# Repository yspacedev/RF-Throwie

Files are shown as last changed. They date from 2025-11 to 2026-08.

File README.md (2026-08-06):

## About
The RF throwie is an ultra-cheap sub-GHz transmitter using the CMOSTek/HopeRF $1 CMT2119A RF transmitter and $0.10 CH32V003 32-bit RISC-V microcontroller on a 20x20mm 2-layer board.

Called a "throwie" because it's designed to be cheap enough (almost disposable) that you can throw it anywhere for a foxhunt or other RF application.

The CMT2119A supports (G)FSK/OOK modulation and a tuning range of 157MHz - 1297MHz (according to G4EML). While it's meant to be configured with CMOSTek's RFPDK and their proprietary software, it can be configured in-situ though a 2-wire interface that writes to registers on the chip. The registers have been partly reverse engineered in https://github.com/g4eml/RP2040_Synth, and this project aims to reverse engineer them more fully to allow for full customization without the RFPDK. The CMT2119A can also be used as a general-purpose frequency synthesizer, which opens up a lot of possibilities for cheap SDRs and custom RF frontends. 

### Firmware

The CH32V003 is programmed with cnlohr's ch32fun stack and uses bitbanging to generate the TWI signals. The current firmware transmits Morse code on the UHF ham radio band (70cm band) that can be picked up by an SDR using NBFM demodulation or a cheap handheld transciever like a Baofeng or Quansheng UV-K5. In theory more modulations are possible, including FSK-based modes. However, due to the long (370us) tuning time and coarse frequency resolution (200~400Hz) of the frequency synthesizer, phase modulation through frequency modulation is likely not possible with unmodified hardware. Maybe using a bitstream to generate harmonics and then filtering before feeding into the reference oscillator input could result in a fine frequency resolution on inexpensive hardware, but this has yet to be tested.

For development and compilation, you will need to set up CH32fun per the instructions on their github. If you use clangd or Microsoft Intellisense with VSCode/VSCodium, those options are already set up, but you will need to change the path for the libraries or use `compiledb make` to generate the `compile_commands.json` file.

### Board/hardware

The RF throwie board itself supports an input voltage of 3.7v - 18v, and has an onboard LED and the CH32V003 UART interface exposed. There are also 2 jumpers on the back that connect the UART pins to the CMT2119A TWI pins to turn it into a breakout board. For the RF chip, there's a up to 7th order LC filter and matching network feeding an SMA connector or simple wire antenna.

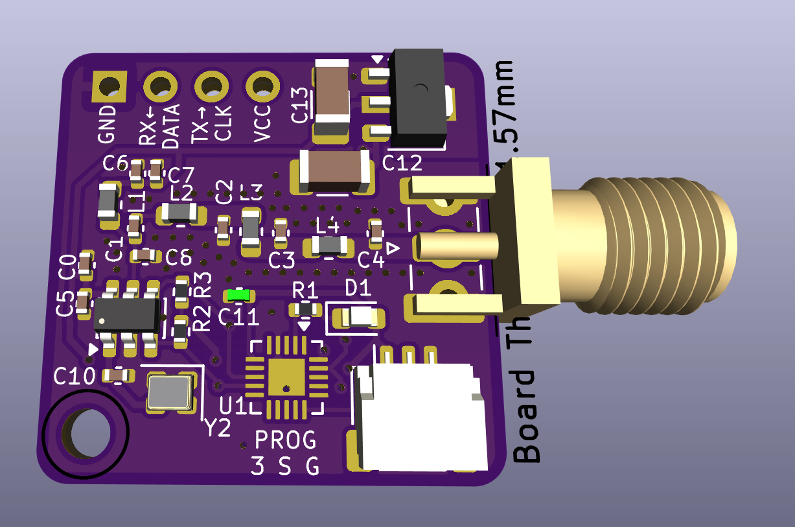
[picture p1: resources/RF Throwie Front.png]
Board Front

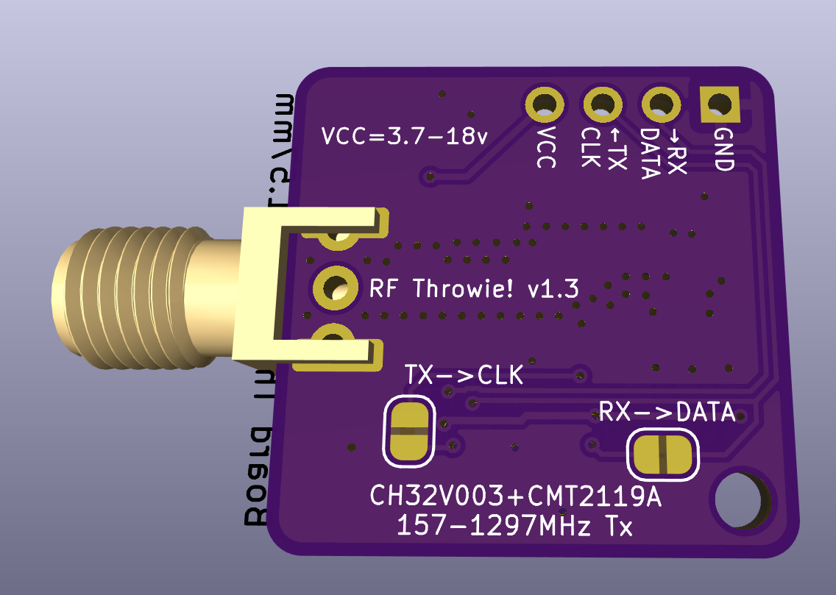
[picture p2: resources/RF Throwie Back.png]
Board Back

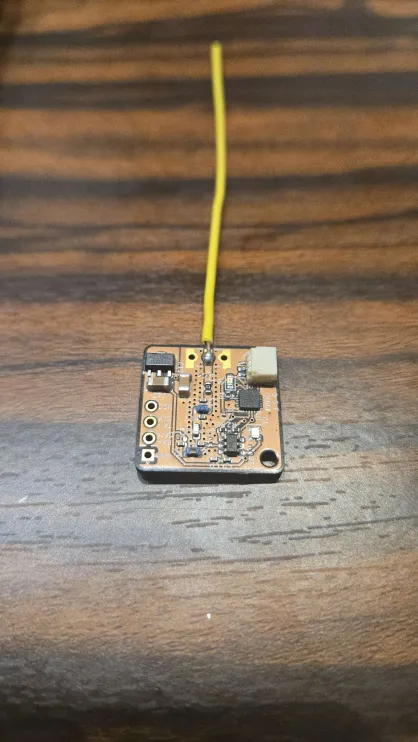
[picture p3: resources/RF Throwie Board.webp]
Board Image


## Tuning

The RF output pin has a frequency dependent impedance, and since CMOSTek only provided the impedance at 4 test frequencies, I used a Python curve fitter to get an empirical equation for the output impedance. This Desmos graph implements the formula: https://www.desmos.com/calculator/a3xyh0sjgi

To create a custom matching network for the transmitter, use https://home.sandiego.edu/~ekim/e194rfs01/jwmatcher/matcher2.html to create a match to 50 ohms and then use https://markimicrowave.com/technical-resources/tools/lc-filter-design-tool/ to generate a filter network.

## Extra Information

Extra information like LCSC part numbers for certain components is included in the KiCAD schematic.

It's designed to be fabricated on a 1.6mm FR4 2 layer board.

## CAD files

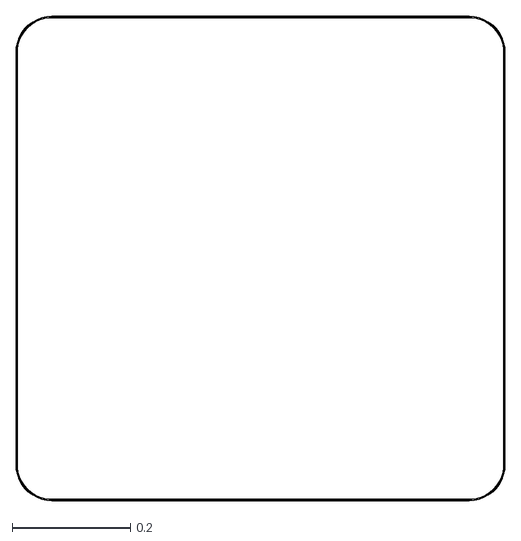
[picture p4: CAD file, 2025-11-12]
hardware/stencil/RF Throwie!-Edge_Cuts.dxf
0.826 x 0.818

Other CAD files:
hardware/stencil/RF Throwie!-F_Paste.dxf

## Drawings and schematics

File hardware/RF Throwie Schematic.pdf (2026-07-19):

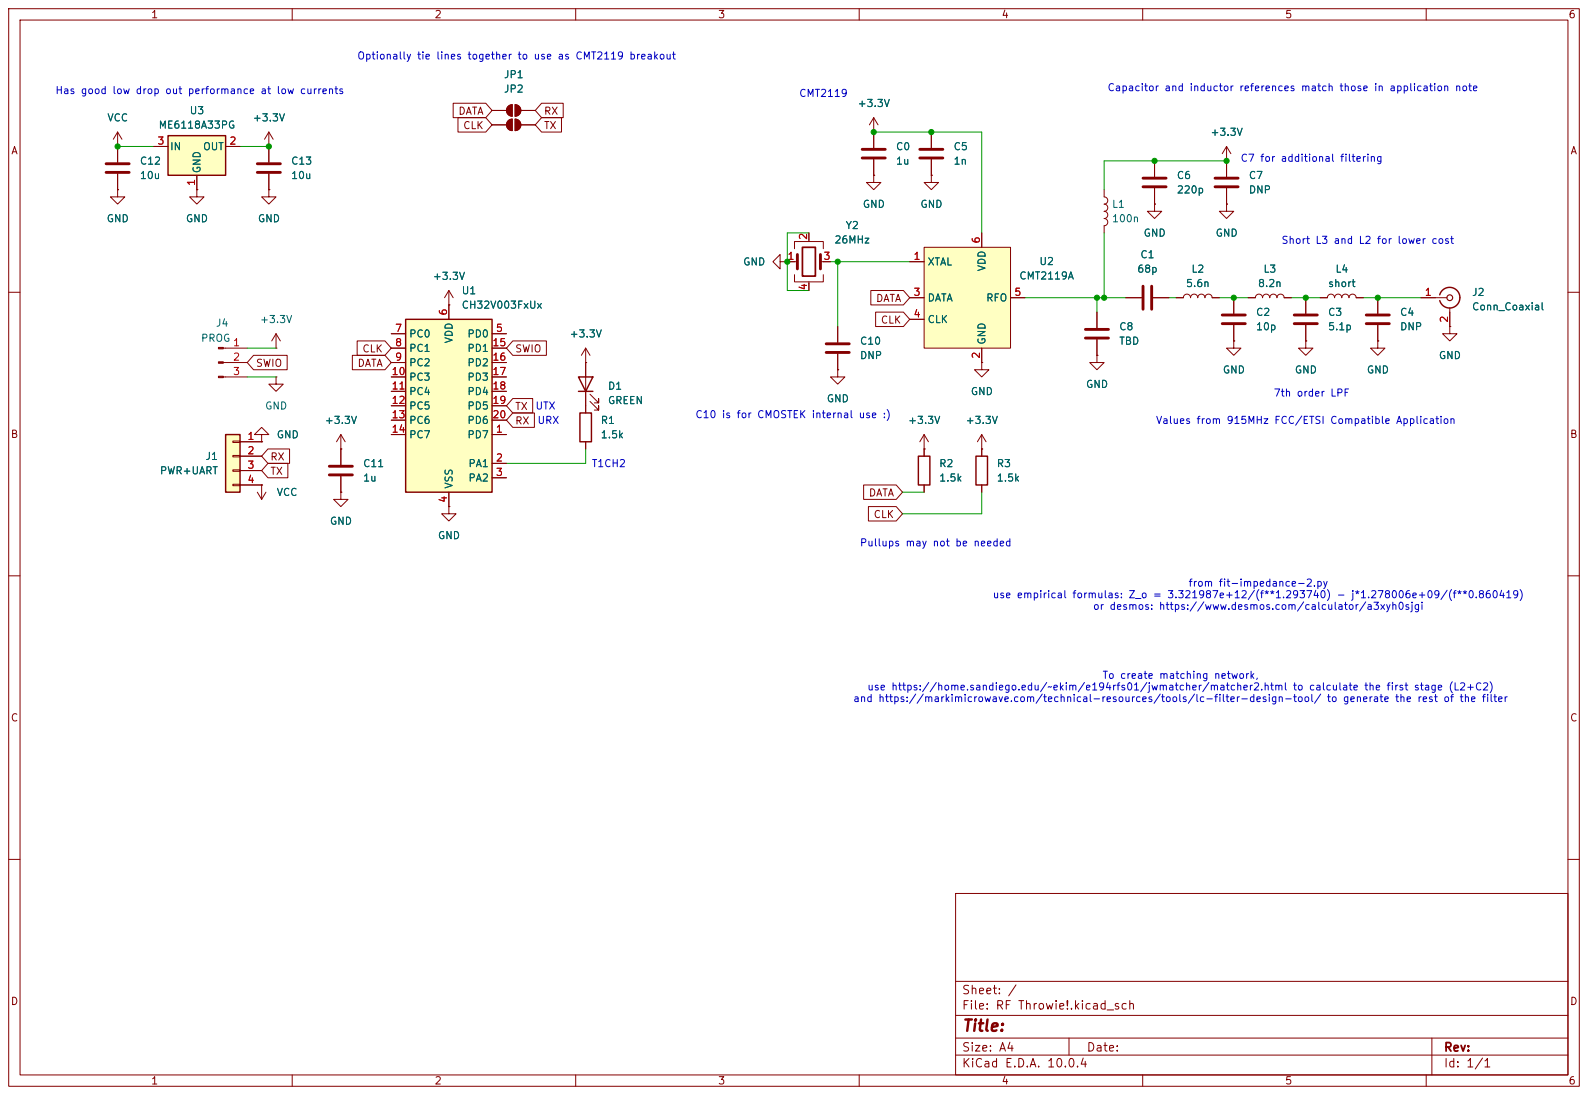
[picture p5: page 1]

Optionally tie lines together to use as CMT2119 breakout

Capacitor and inductor references match those in application note Pullups may not be needed
26MHzGND +3.3V C0

2 DATA 3 CLK 4 RFO 5 VDD

from fit-impedance-2.py use empirical formulas: Z_o = 3.321987e+12/(f**1.293740) - j*1.278006e+09/(f**0.860419) or desmos: https://www.desmos.com/calculator/a3xyh0sjgi

To create matching network, use https://home.sandiego.edu/~ekim/e194rfs01/jwmatcher/matcher2.html to calculate the first stage (L2+C2) and https://markimicrowave.com/technical-resources/tools/lc-filter-design-tool/ to generate the rest of the filter

Size: A4 | Rev:
KiCad E.D.A. 10.0.4 | Id: 1/1

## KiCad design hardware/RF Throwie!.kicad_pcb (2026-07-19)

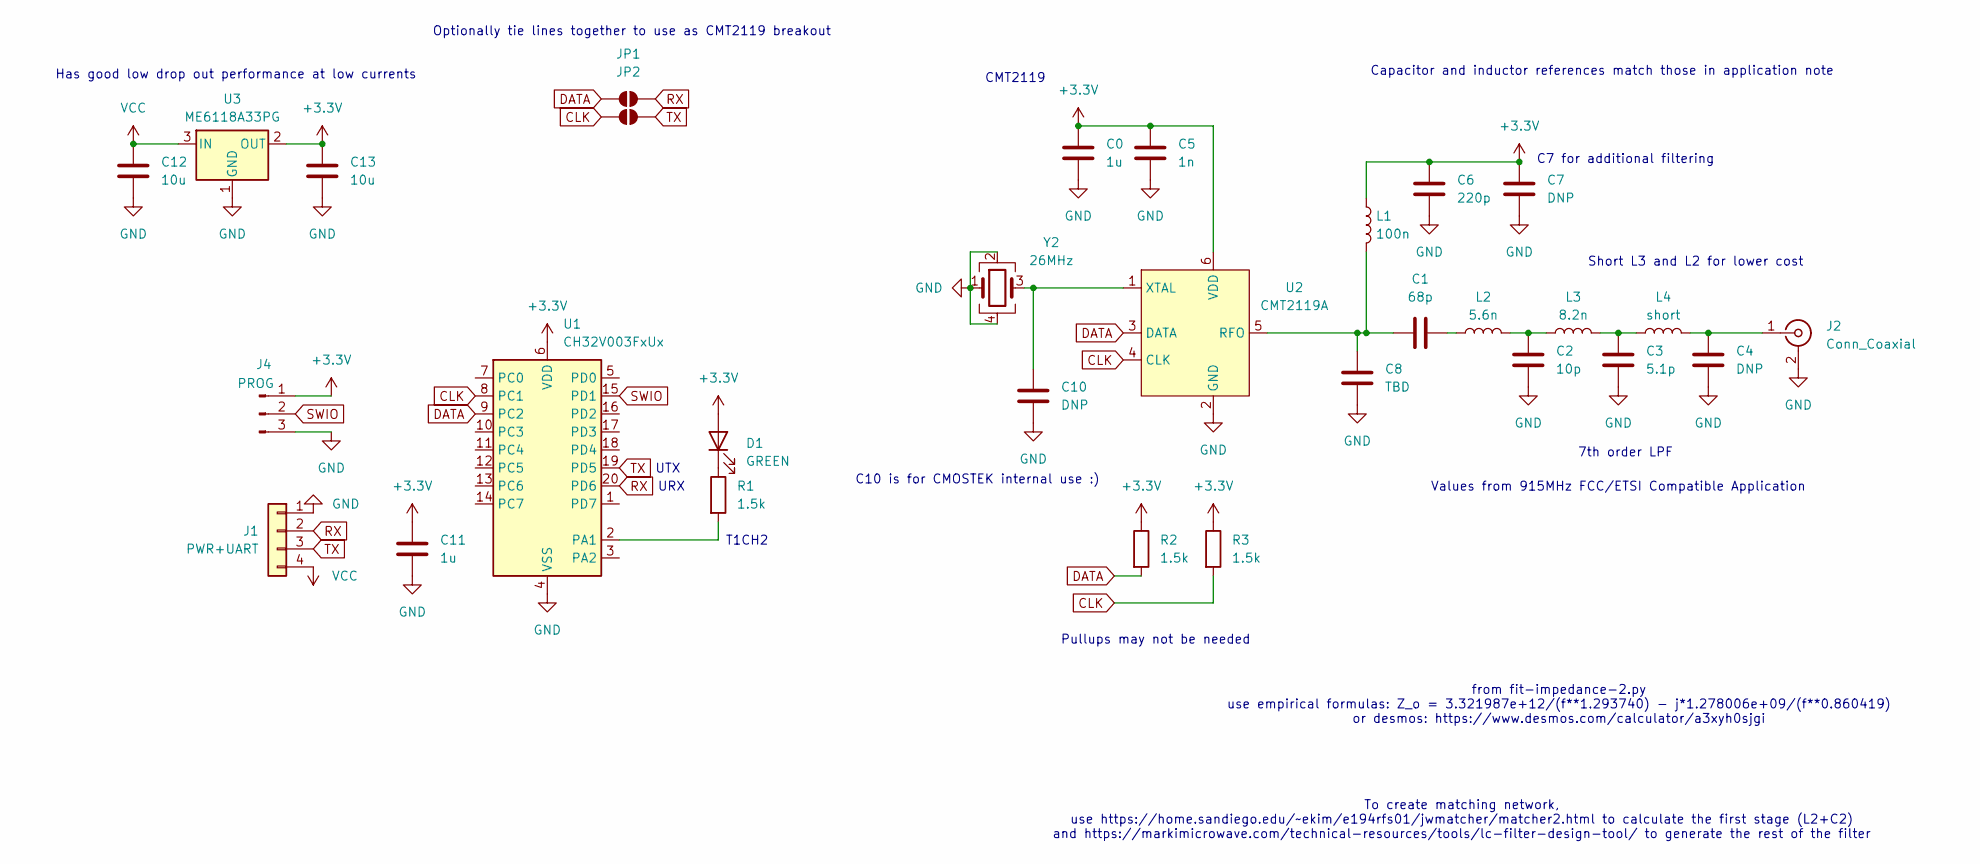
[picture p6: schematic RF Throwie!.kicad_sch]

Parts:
C0, C11: 1u; C_0402_1005Metric
C1: 68p; C_0402_1005Metric
C2: 10p; C_0402_1005Metric
C3: 5.1p; C_0402_1005Metric
C4, C7, C10: DNP; C_0402_1005Metric
C5: 1n; C_0402_1005Metric
C6: 220p; C_0402_1005Metric
C8: TBD; C_0402_1005Metric
C12, C13: 10u; C_1206_3216Metric
D1: GREEN; LED_0603_1608Metric
J1: PWR+UART; PinHeader_1x04_P2.54mm_Vertical
J2: Conn_Coaxial; SMA_Samtec_SMA-J-P-H-ST-EM1_EdgeMount
J4: PROG; JST_SH_SM03B-SRSS-TB_1x03-1MP_P1.00mm_Horizontal
JP1, JP2: SolderJumper_2_Open; SolderJumper-2_P1.3mm_Open_RoundedPad1.0x1.5mm
L1: 100n; L_0603_1608Metric
L2: 5.6n; L_0603_1608Metric
L3: 8.2n; L_0603_1608Metric
L4: short; L_0603_1608Metric
R1, R2, R3: 1.5k; R_0402_1005Metric
U1: CH32V003FxUx; QFN-20-1EP_3x3mm_P0.4mm_EP1.65x1.65mm; LCSC Part Number C5299908
U2: CMT2119A; SOT-23-6; LCSC Part Number C77214
U3: ME6118A33PG; SOT-89-3; LCSC Part Number C236721
Y2: 26MHz; Crystal_SMD_2016-4Pin_2.0x1.6mm; LCSC Part Number C2933002

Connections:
+3.3V: C0.1, C5.1, C6.1, C7.1, C11.1, C13.1, D1.2 (A), J4.1, L1.1, R2.1, R3.1, U1.6 (VDD), U2.6 (VDD), U3.2 (OUT)
CLK: JP2.1 (A), R3.2, U1.8 (PC1), U2.4 (CLK)
DATA: JP1.1 (A), R2.2, U1.9 (PC2), U2.3 (DATA)
GND: C0.2, C2.2, C3.2, C4.2, C5.2, C6.2, C7.2, C8.2, C10.2, C11.2, C12.2, C13.2, J1.1, J2.2 (Ext), J4.3, U1.4 (VSS), U1.21 (VSS), U2.2 (GND), U3.1 (GND), Y2.1, Y2.2, Y2.4
unnamed: C1.2, L2.1
unnamed: C2.1, L2.2, L3.1
unnamed: C3.1, L3.2, L4.1
unnamed: D1.1 (K), R1.1
unnamed: C4.1, J2.1 (In), L4.2
unnamed: R1.2, U1.2 (PA1)
unnamed: C1.1, C8.1, L1.2, U2.5 (RFO)
unnamed: C10.1, U2.1 (XTAL), Y2.3
RX: J1.2, JP1.2 (B), U1.20 (PD6)
SWIO: J4.2, U1.15 (PD1)
TX: J1.3, JP2.2 (B), U1.19 (PD5)
VCC: C12.1, J1.4, U3.3 (IN)

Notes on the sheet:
CMT2119
C10 is for CMOSTEK internal use :)
Pullups may not be needed
7th order LPF
Capacitor and inductor references match those in application note
URX
Has good low drop out performance at low currents
UTX
T1CH2
To create matching network, use https://home.sandiego.edu/~ekim/e194rfs01/jwmatcher/matcher2.html to calculate the first stage (L2+C2) and https://markimicrowave.com/technical-resources/tools/lc-filter-design-tool/ to generate the rest of the filter
C7 for additional filtering
Short L3 and L2 for lower cost
Optionally tie lines together to use as CMT2119 breakout
Values from 915MHz FCC/ETSI Compatible Application
from fit-impedance-2.py use empirical formulas: Z_o = 3.321987e+12/(f**1.293740) - j*1.278006e+09/(f**0.860419) or desmos: https://www.desmos.com/calculator/a3xyh0sjgi

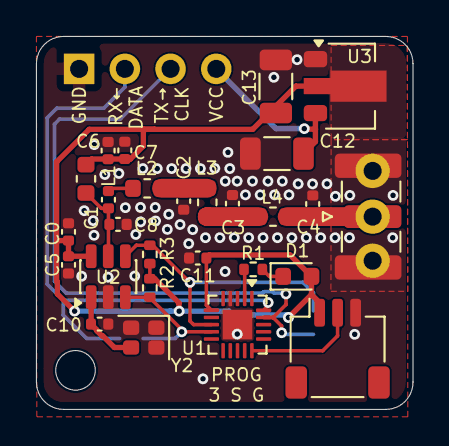
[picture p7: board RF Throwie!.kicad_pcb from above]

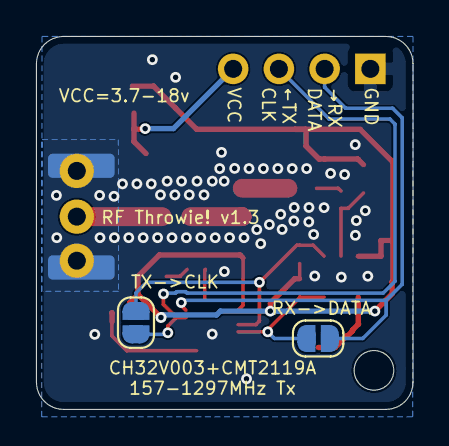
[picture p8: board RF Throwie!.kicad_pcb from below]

Board: 2 copper layers, 20.9 x 20.7 mm, 30 parts (2 on the bottom side), 16 nets.

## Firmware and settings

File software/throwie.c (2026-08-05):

#include "ch32fun.h"
#include "CMT2119A.h"
#include "CMT2119A_TWI.h"
#include "ch32v003hw.h"

#define TONE_HZ 1000
#define CTR_RELOAD (2000000/TONE_HZ)
#define MORSE_WPM 20
//50 units in the word "PARIS"
//50*WPM is the number of units per minute (1/(50*WPM))*MS_PER_MINUTE
#define MORSE_UNIT_MS ((60*1000)/(50*MORSE_WPM))

const char* morse_string = "CALLSIGN TEST"; //replace with your own callsign or change TX_FREQ to an ISM band

//possibly rearrange to map better onto ascii
const char* MORSE_ALPHABET[] = {
    ".-",   // A
    "-...", // B
    "-.-.", // C
    "-..",  // D
    ".",    // E
    "..-.", // F
    "--.",  // G
    "....", // H
    "..",   // I
    ".---", // J
    "-.-",  // K
    ".-..", // L
    "--",   // M
    "-.",   // N
    "---",  // O
    ".--.", // P
    "--.-", // Q
    ".-.",  // R
    "...",  // S
    "-",    // T
    "..-",  // U
    "...-", // V
    ".--",  // W
    "-..-", // X
    "-.--", // Y
    "--..", // Z
	"-----",// 0
	".----",// 1
	"..---",// 2
	"...--",// 3
	"....-",// 4
	".....",// 5
	"-....",// 6
	"--...",// 7
	"---..",// 8
	"----.",// 9
};

char upper(char c){
	if (c>='a' && c<='z'){
		return c - 20;
	}
	return c;
}

uint8_t morse_lookup(char c){
	uint8_t idx = 0;
	char up_char = (char)upper((int)c);
	if (up_char >= '0' && up_char <= '9') {
		idx=up_char-'0'+26;
	} else if (up_char >= 'A' && up_char <= 'Z'){
		idx=up_char-'A';
	}
	return idx;
}

void morse_char(char char_in){
	if (char_in==' '){
		Delay_Ms(6*MORSE_UNIT_MS); //6 units instead of 7 since 1 unit delay comes after every dit or dah
		return;
	}
	uint8_t idx = morse_lookup(char_in);
	
	if (idx>=(sizeof(MORSE_ALPHABET)/sizeof(char*))) return;
	char* code = (char*)MORSE_ALPHABET[idx];
	char c = *code;
	while (c!=0){
		int sym = 1;
		if (c=='.'){
			sym=1;
		} else if (c=='-') {
			sym=3;
		}
		funPinMode(TWIDAT, GPIO_Speed_10MHz | GPIO_CNF_OUT_PP_AF); //switch to timer output
		TIM2->CTLR1 |= TIM_CEN; //enable timer
		Delay_Ms(sym*MORSE_UNIT_MS);
		TIM2->CTLR1 &= ~TIM_CEN; //disable timer
		funPinMode(TWIDAT, FUN_OUTPUT); //switch back to GPIO
		TWI_DAT_HIGH //keep high to prevent transmitter going into sleep mode

		code++;
		c=*code;
		Delay_Ms(1*MORSE_UNIT_MS);
	}
	Delay_Ms(2*MORSE_UNIT_MS);
}

void encode_morse(const char *str){
	char c = *str;
	while (c!=0){
		morse_char(c);
		str++;
		c=*str;
	}
}

//use a timer to modulate the FSK into a continuous tone
void init_tone_timer(void){
	//PC2 has alternate remapping to T2CH2

	//enable AFIO and TIM2
	RCC->APB2PCENR |= RCC_APB2Periph_AFIO | RCC_APB2Periph_GPIOC;
	RCC->APB1PCENR |= RCC_APB1Periph_TIM2;

	//remap alternate function
	AFIO->PCFR1 |= AFIO_PCFR1_TIM2_REMAP_PARTIALREMAP1;

	//reset TIM2
	RCC->APB1PRSTR |= RCC_APB1Periph_TIM2;
	RCC->APB1PRSTR &= ~RCC_APB1Periph_TIM2;

	//Set prescaler
	TIM2->PSC = 23; //divide by 24
	
	TIM2->ATRLR = CTR_RELOAD;

	TIM2->CHCTLR1 |= TIM_OC2M_2 | TIM_OC2M_1 | TIM_OC2PE;

	TIM2->CH2CVR = CTR_RELOAD/2;

	TIM2->CTLR1 |= TIM_ARPE;

	TIM2->CCER |= TIM_CC2E | TIM_CC2P;

	TIM2->SWEVGR |= TIM_UG; //initialize counter
}


#define LED PA1
#define UART_TX PD5
#define UART_RX PD6

int main(){
	SystemInit();

	funGpioInitAll(); // Enable GPIOs
	init_tone_timer();
	funPinMode(LED, FUN_OUTPUT);
	funPinMode(PC2, GPIO_Speed_10MHz | GPIO_CNF_OUT_PP_AF);

	CMT2119A_settings_t tx_settings = {
		.freq_out_hz = 430100000,
		.fsk_dev_hz = 2000,
		.gfsk_rate_bps = 1600, //minimum required for 1khz tone in GFSK mode
		.power_output_dbm = -10,
		.modulation = MOD_FSK,
		.off_time = OFF_90MS,
		.pa_ramp_time = 0,
		.edge_start = EDGE_RISING,
		.invert_symbols = false,
		.xo_current_boost = false,
	};

	CMT2119A_init(PC1, PC2, &tx_settings); //use default frequency

	while(1)
	{
		funDigitalWrite(LED, FUN_LOW);
		//CMT2119A_update(); 
		//frequency can also be changed live, but transmitting the PLL parameters takes more time if we don't need to do so
		TWI_reset();
		Delay_Ms(2);
		CMT2119A_TWI_OFF();
		TWI_DAT_HIGH //wake up from sleep mode
		Delay_Us(1);
		TWI_DAT_LOW
		encode_morse(morse_string);
		TWI_reset(); //turns transmitter off
		//to transmit continuously, leave the DAT pin high
		funDigitalWrite(LED, FUN_HIGH);
		Delay_Ms(1000);
	}
}

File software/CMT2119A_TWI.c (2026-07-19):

#include "CMT2119A_TWI.h"

 uint8_t TWICLK = PC1;
 uint8_t TWIDAT = PC2;

void TWI_init(uint8_t clk_pin, uint8_t dat_pin){
    funGpioInitAll();
    TWICLK = clk_pin;
    TWIDAT = dat_pin;
    TWI_DAT_OUT
    TWI_CLK_OUT
    TWI_DAT_HIGH
    TWI_CLK_HIGH
}


void TWI_Write(uint8_t x){
    TWI_CLK_HIGH
    TWI_DAT_LOW
    for(uint8_t i=0; i<8; ++i){
        TWI_CLK_HIGH
        if(x & 0x80) TWI_DAT_HIGH else TWI_DAT_LOW
        TWI_CYCLE_DELAY
        funDigitalWrite(TWICLK,FUN_LOW); 
        TWI_CYCLE_DELAY
        x<<=1;
    }
    TWI_CLK_HIGH
    TWI_DAT_LOW
}

uint8_t TWI_Read(void){
    uint8_t r=0;
    TWI_DAT_IN
    TWI_CLK_HIGH
    for(uint8_t i=0; i<8; ++i){
        TWI_CLK_HIGH
        TWI_CYCLE_DELAY
        r <<= 1;
        funDigitalWrite(TWICLK,FUN_LOW);
        TWI_CYCLE_DELAY
        if(TWI_DAT_READ) r|=1;
    }
    TWI_CLK_HIGH
    TWI_DAT_OUT
    funDigitalWrite(TWIDAT,FUN_LOW);
    return r;
}


void TWI_WRREG(uint8_t addr, uint8_t data){
    TWI_Write(0x80|(addr&0x3f));
    TWI_Write(data);
}

uint8_t TWI_RDREG(uint8_t addr){
    TWI_Write(0xc0|(addr&0x3f));
    return TWI_Read();
}


void TWI_RAM1(uint8_t addr, uint16_t data){
    TWI_WRREG(0x18,addr);
    TWI_WRREG(0x19,data&0xff);
    TWI_WRREG(0x1A,data>>8);
    TWI_WRREG(0x25, 0x01);
}

void TWI_RAM(const uint32_t *x, uint8_t n){
    for(uint8_t i=0; i<n; ++i){
        TWI_RAM1(i,*x++);
    }
}

void TWI_reset(void){
    TWI_DAT_LOW
    TWI_CLK_HIGH
    TWI_CYCLE_DELAY

    for(uint8_t i=0; i<32; ++i){
	    funDigitalWrite(TWICLK,FUN_LOW);
	    TWI_CYCLE_DELAY
	    TWI_CLK_HIGH
        TWI_CYCLE_DELAY	
	}
    //send TWI_RST
    TWI_Write(0x8D);
    TWI_Write(0x00);
}

void CMT2119A_SOFT_RST(void){
    TWI_Write(0xBD);
    TWI_Write(0x01);
}

void CMT2119A_TWI_OFF(void){
    TWI_Write(0x8D);
    TWI_Write(0x02);
}

void CMT2119A_RESET(void){
    TWI_reset(); //step 1
    TWI_WRREG(0x3d, 0x01); //step 2 send SOFT_RST
    TWI_MS_DELAY
    TWI_MS_DELAY
    TWI_WRREG(0x0D, 0x02); //step 7 send the TWI_OFF command. Control reverts to simple DAT signals
}

void TWI_EEPROM_ERASE(uint8_t add){
    uint8_t resp;
    TWI_WRREG(0x17,add);          //Set the EEPROM Address
    TWI_WRREG(0x16,0x39);           //start the erase
    do                          //wait till the erase has completed
    {
        TWI_MS_DELAY
        resp = TWI_RDREG(0x1F);
    }
    while ((resp & 0x08) == 0); 
    TWI_WRREG(0x16,0x31);           //end the erase
}

void TWI_EEPROM_WRITE(uint8_t add, uint16_t dat){
    uint8_t resp;
    TWI_WRREG(0x17,add);          //Set the EEPROM Address
    TWI_WRREG(0x19,dat & 0xFF);   //Set the EEPROM Low Byte
    TWI_WRREG(0x1A,dat >> 8);     //Set the EEPROM High Byte 
    TWI_WRREG(0x16,0x35);         //start the write
    do {                            //wait till the erase has completed
        TWI_MS_DELAY
        resp = TWI_RDREG(0x1F);
    } while ((resp & 0x08) == 0); 
    TWI_WRREG(0x16,0x31);           //end the write
}

uint16_t TWI_EEPROM_READ(uint8_t add){
    uint8_t resp;
    uint16_t val;
    TWI_WRREG(0x17,add);          //Set the EEPROM Address 
    TWI_WRREG(0x16,0x33);         //start the read
    do {
        TWI_MS_DELAY
        resp = TWI_RDREG(0x1F);
    } while ((resp & 0x08) == 0); 
    val =(TWI_RDREG(0x1C) <<8) + TWI_RDREG(0x1B) ;
    TWI_WRREG(0x16,0x31);           //end the read
    return val;
}

void TWI_EEPROM_SETUP(void){
    TWI_WRREG(0x02,0x3B);
    TWI_WRREG(0x2F,0x80);
    TWI_WRREG(0x3F,0x01);
    TWI_WRREG(0x16,0x31);
    TWI_WRREG(0x35,0xCA);
    TWI_WRREG(0x36,0xEB);
    TWI_WRREG(0x37,0x37);
    TWI_WRREG(0x38,0x82);        
}

void TWI_EEPROM_END(void){
    TWI_WRREG(0x16,0x30);
    TWI_WRREG(0x3F,0x00);
    TWI_WRREG(0x0C,0x27);
    TWI_WRREG(0x2F,0x00);
    TWI_WRREG(0x02,0x7F);
    TWI_WRREG(0x0C,0x00);
    TWI_WRREG(0x3D,0x01);         //SOFT_RESET.  
}

//Burn the Chips built in EEPROM. Sequence copied originally from official programmer and then trimmed. 

void CMT2119A_EEPROM_BURN(uint16_t* regmap){
    printf("Burn and Verify Start\n");
    TWI_reset();
    TWI_reset();
    TWI_EEPROM_SETUP();
    for(int r=0;r<0x15;r++){           //erase and write EEPROM values 0x00 - 0x14 
        TWI_EEPROM_ERASE(r);
        TWI_EEPROM_WRITE(r, regmap[r]);
    }

    for(int r=0;r<0x15;r++){           //verify the EEPROM values 0x00 - 0x14
        uint16_t val = TWI_EEPROM_READ(r);
        if( val!= regmap[r]){
            printf("Verify Error at address = ");
            printf("%#02X", r);
            printf(" Value = ");
            printf("%#02X\n", val);
        }
    }
    TWI_EEPROM_END();
    printf("Burn and Verify Complete\n");

    printf("Resetting from CMT2119A EEPROM"); 
    CMT2119A_RESET();
    TWI_DAT_HIGH
}

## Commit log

2025-11-12 Initial Commit!
    [RF Throwie!-Edge_Cuts.dxf, RF Throwie!-F_Paste.dxf, RF Throwie!.kicad_pcb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]
2025-11-12 Add PDF schematic
2025-11-13 Add RX->DATA and TX->CLK jumpers, add more helpful silkscreen, fix SMA connector footprint
    [RF Throwie!.kicad_pcb, RF Throwie!.kicad_sch]
2026-07-19 First working firmware, update KiCAD, update README
    [RF Throwie!-B_Cu.gbr, RF Throwie!-B_Mask.gbr, RF Throwie!-B_Silkscreen.gbr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]
